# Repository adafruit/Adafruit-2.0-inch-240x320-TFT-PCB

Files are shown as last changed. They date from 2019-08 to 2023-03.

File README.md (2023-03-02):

## Adafruit 2.0" 320x240 Color IPS TFT Display with microSD Card Breakout PCB

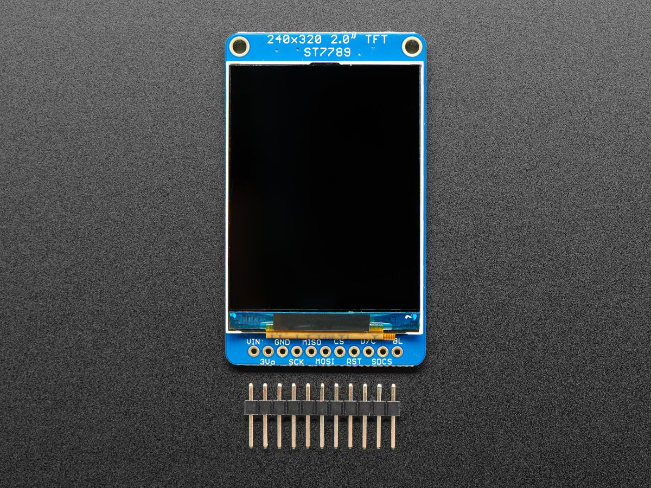
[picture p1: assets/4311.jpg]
<a href="http://www.adafruit.com/products/4311"><br/>
Click here to purchase one from the Adafruit shop</a>

PCB files for the Adafruit 2.0" 320x240 Color IPS TFT Display with microSD Card Breakout. 

Format is EagleCAD schematic and board layout
* https://www.adafruit.com/product/4311

### Description

This gorgeous IPS display breakout is the best way to add a small, colorful, and bright display to any project, with excellent visibility from any angle. Since the display uses 4-wire SPI to communicate and has its own pixel-addressable frame buffer, it can be used with every kind of microcontroller. Even a very small one with low memory and few pins available!

The 2.0" display has 320x240 color pixels. Unlike the low cost "Nokia 6110" and similar LCD displays, which are CSTN type and thus have poor color and slow refresh, this display is a true TFT! Not only that, but its an IPS display for vivid color and high-angle visibility. The TFT driver (ST7789) can display full 18-bit color (262,144 shades), but almost all drivers will use just 16-bit color. The TFT will always come with the same driver chip so there's no worries that your code will not work from one to the other.

The breakout has the TFT display soldered on (it uses a delicate flex-circuit connector) as well as a ultra-low-dropout 3.3V regulator, auto-reset circuitry, and a 3/5V level shifter so you can use it with 3.3V or 5V power and logic. We also had a little space so we placed a microSD card holder so you can easily load full color bitmaps from a FAT16/FAT32 formatted microSD card. The microSD card is not included, but you can pick one up here.

Of course, we wouldn't just leave you with a datasheet and a "good luck!" - we've written a full open source graphics library that can draw pixels, lines, rectangles, circles, text, and bitmaps as well as example code. The code is written for Arduino but can be easily ported to your favorite microcontroller! Wiring is easy, we strongly encourage using the hardware SPI pins of your Arduino as software SPI is noticeably slower when dealing with this size display.

New! As of February 2023, this display breakout also features an 18-pin "EYESPI" standard FPC connector with flip-top connector. You can use an 18-pin 0.5mm pitch FPC cable to connect to the display over SPI and I2C, respectively. Great for when you want to skip soldering all those headers. 

### License

Adafruit invests time and resources providing this open source design, please support Adafruit and open-source hardware by purchasing products from [Adafruit](https://www.adafruit.com)!

Designed by Limor Fried/Ladyada for Adafruit Industries.

Creative Commons Attribution/Share-Alike, all text above must be included in any redistribution. 
See license.txt for additional details.

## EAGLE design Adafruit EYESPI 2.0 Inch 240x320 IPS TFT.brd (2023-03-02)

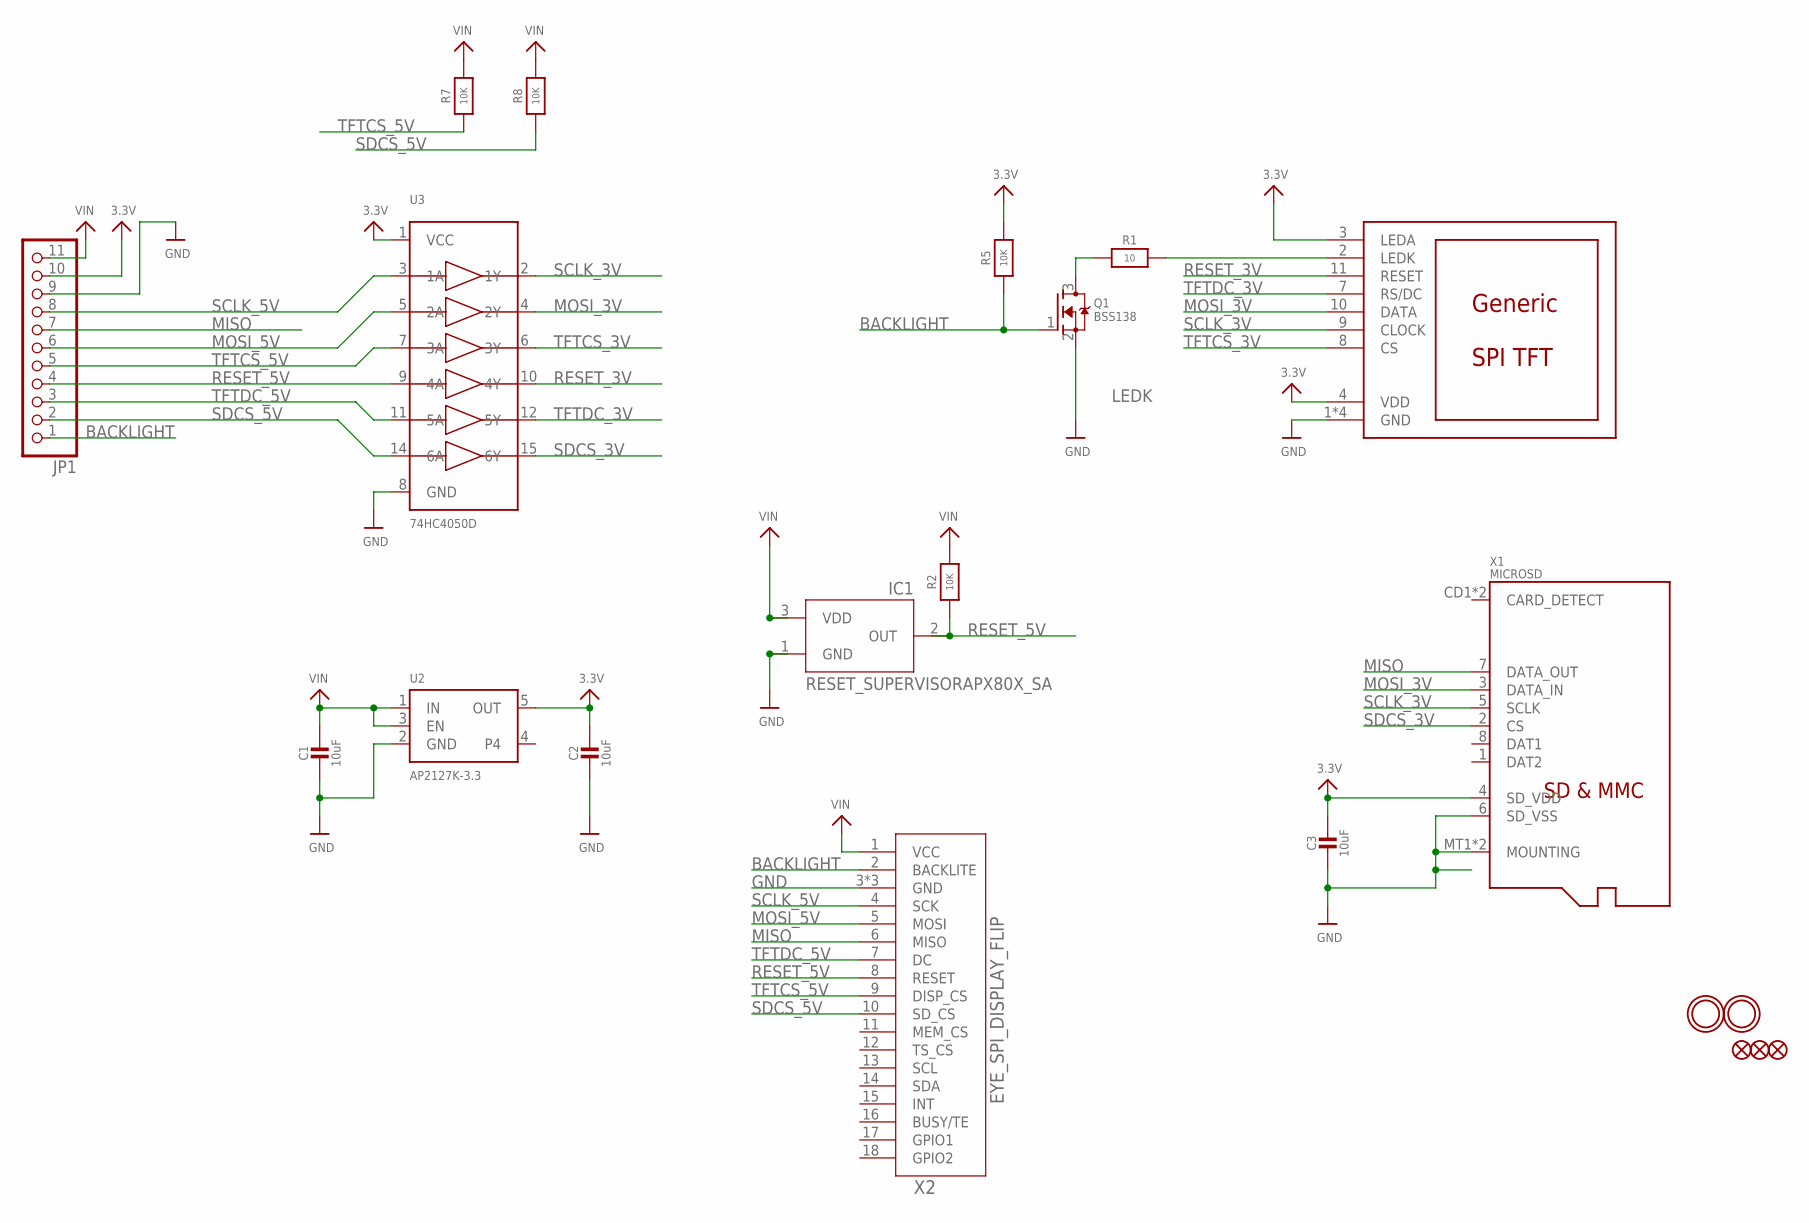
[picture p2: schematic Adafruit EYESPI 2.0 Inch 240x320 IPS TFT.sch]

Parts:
C1, C2, C3: 10uF; 0805-NO
DISP1: DISP_LCD_GENERIC_SPI_2.0IN_240X320; TFT_2.0IN_240X320_12P
FID1, FID2, FID3: FIDUCIAL_1MM
IC1: RESET_SUPERVISORAPX80X_SA; SOT23-WIDE
JP1: HEADER-1X1176MIL; 1X11_ROUND_76
Q1: BSS138; SOT23-R
R1: 10; 0805-NO
R2, R5, R7, R8: 10K; 0805-NO
U2: AP2127K-3.3; SOT23-5
U3: 74HC4050D; SOIC16
U$3, U$4: MOUNTINGHOLE2.5; MOUNTINGHOLE_2.5_PLATED
X1: MICROSD
X2: EYE_SPI_DISPLAY_FLIP; EYE_SPI_DISPLAY_BOTCONTACT

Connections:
3.3V: C2.1, C3.1, DISP1.3 (LEDA), DISP1.4 (VDD), JP1.10, R5.2, U2.5 (OUT), U3.1 (VCC), X1.4 (SD_VDD)
BACKLIGHT: JP1.1, Q1.1 (G), R5.1, X2.2 (BACKLITE)
GND: C1.2, C2.2, C3.2, DISP1.1 (GND), DISP1.5 (GND), DISP1.6 (GND), DISP1.12 (GND), IC1.1 (GND), JP1.9, Q1.2 (S), U2.2 (GND), U3.8 (GND), X1.6 (SD_VSS), X1.MT1 (MOUNTING), X1.MT2 (MOUNTING), X2.3 (GND), X2.SUPPORT1 (GND), X2.SUPPORT2 (GND)
LEDK: Q1.3 (D), R1.1
MISO: JP1.7, X1.7 (DATA_OUT), X2.6 (MISO)
MOSI_3V: DISP1.10 (DATA), U3.4 (2Y), X1.3 (DATA_IN)
MOSI_5V: JP1.6, U3.5 (2A), X2.5 (MOSI)
unnamed: DISP1.2 (LEDK), R1.2
RESET_3V: DISP1.11 (RESET), U3.10 (4Y)
RESET_5V: IC1.2 (OUT), JP1.4, R2.1, U3.9 (4A), X2.8 (RESET)
SCLK_3V: DISP1.9 (CLOCK), U3.2 (1Y), X1.5 (SCLK)
SCLK_5V: JP1.8, U3.3 (1A), X2.4 (SCK)
SDCS_3V: U3.15 (6Y), X1.2 (CS)
SDCS_5V: JP1.2, R8.1, U3.14 (6A), X2.10 (SD_CS)
TFTCS_3V: DISP1.8 (CS), U3.6 (3Y)
TFTCS_5V: JP1.5, R7.1, U3.7 (3A), X2.9 (DISP_CS)
TFTDC_3V: DISP1.7 (RS/DC), U3.12 (5Y)
TFTDC_5V: JP1.3, U3.11 (5A), X2.7 (DC)
VIN: C1.1, IC1.3 (VDD), JP1.11, R2.2, R7.2, R8.2, U2.1 (IN), U2.3 (EN), X2.1 (VCC)

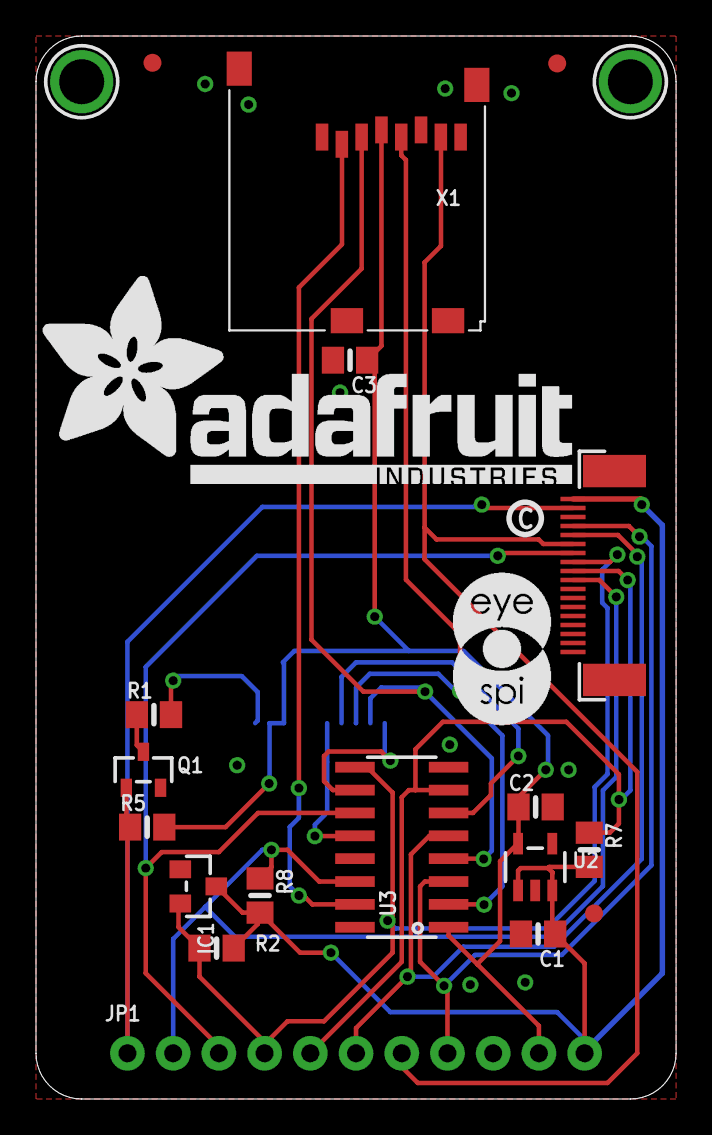
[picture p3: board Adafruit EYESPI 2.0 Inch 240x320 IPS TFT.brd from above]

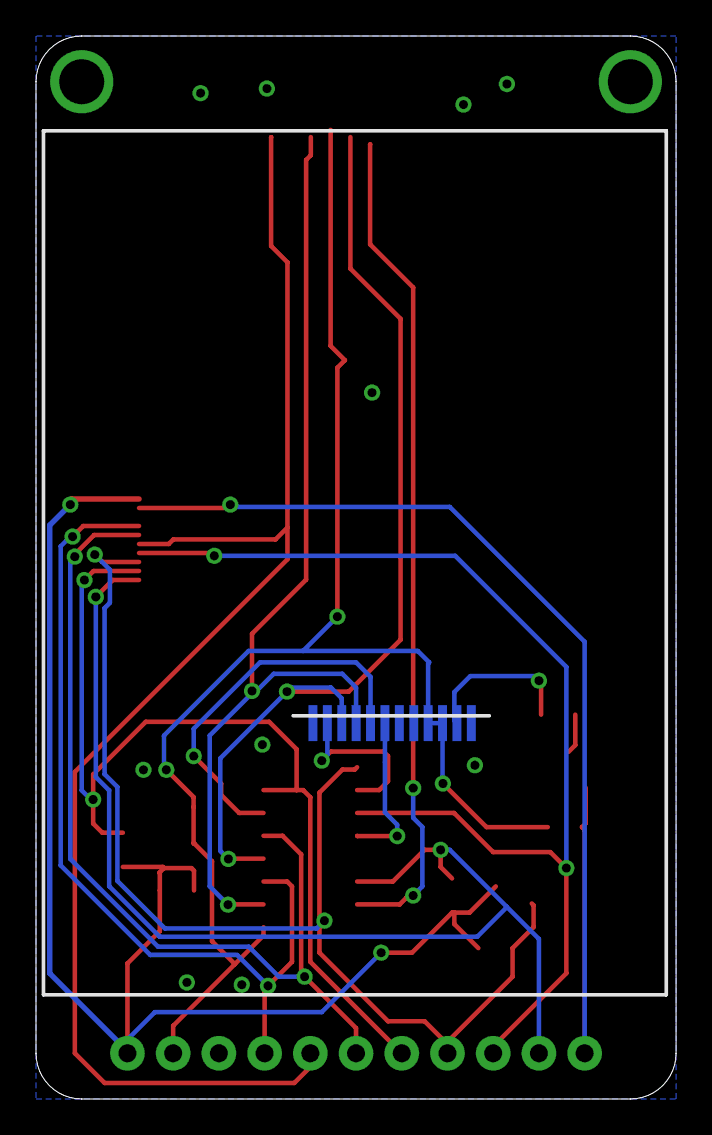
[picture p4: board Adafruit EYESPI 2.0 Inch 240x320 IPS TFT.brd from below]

Board: 2 copper layers, 35.6 x 59.1 mm, 48 parts (13 on the bottom side), 19 nets.

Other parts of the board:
PLABEL0: PLABEL0
PLABEL1: PLABEL1
PLABEL2: PLABEL2
PLABEL3: PLABEL3
PLABEL4: PLABEL4
PLABEL5: PLABEL5
PLABEL6: PLABEL6
PLABEL7: PLABEL7
PLABEL8: PLABEL8
PLABEL9: PLABEL9
PLABEL10: PLABEL10
PLABEL11: PLABEL11
PLABEL12: PLABEL12
PLABEL13: PLABEL13
PLABEL14: PLABEL14
PLABEL15: PLABEL15
PLABEL16: PLABEL16
PLABEL17: PLABEL17
PLABEL18: PLABEL18
PLABEL19: PLABEL19
PLABEL20: PLABEL20
PLABEL21: PLABEL21
PLABEL22: PLABEL22
PLABEL23: PLABEL23
U$20: ADAFRUIT_TEXT_30MM
U$24: PCBFEAT-REV-040
U$28: EYESPI_MINI_LOGO

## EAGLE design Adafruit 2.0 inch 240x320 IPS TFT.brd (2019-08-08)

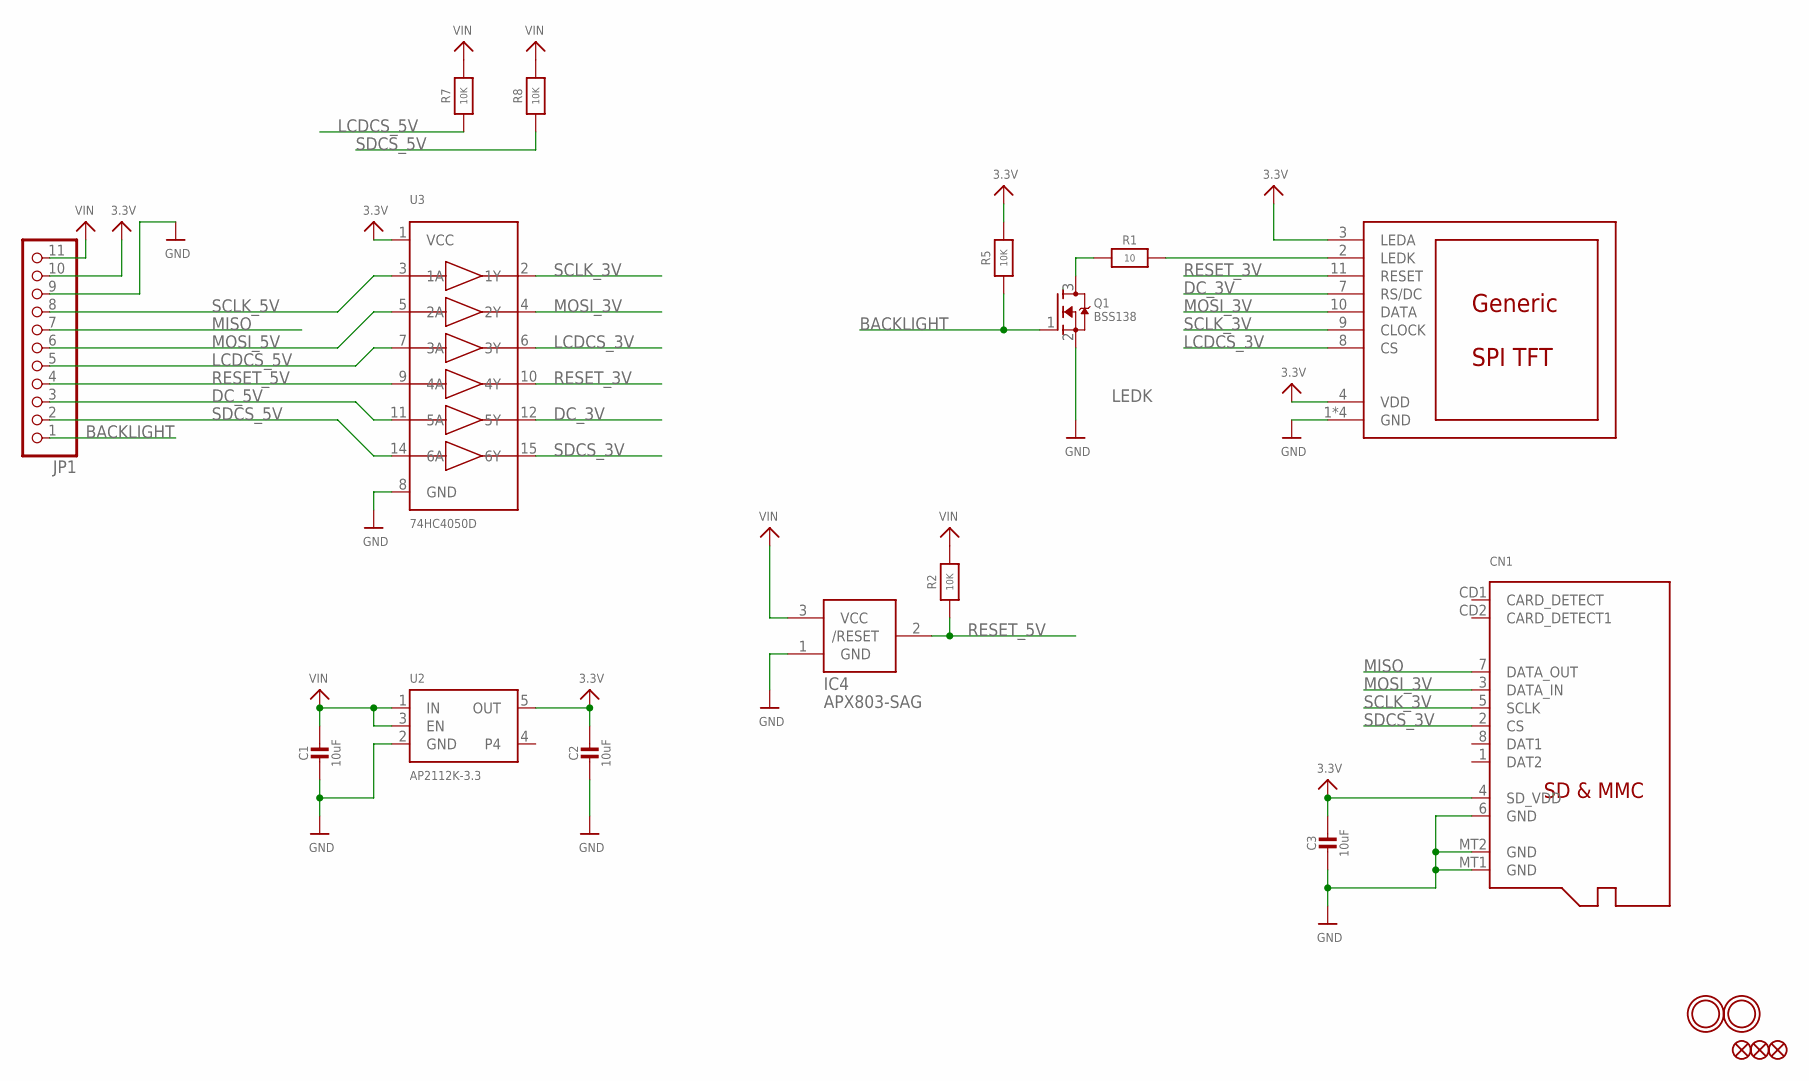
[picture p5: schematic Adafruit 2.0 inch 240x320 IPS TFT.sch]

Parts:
C1, C2, C3: 10uF; 0805-NO
CN1: MICROSD
DISP1: DISP_LCD_GENERIC_SPI_2.0IN_240X320; TFT_2.0IN_240X320_12P
FID1, FID2, FID3: FIDUCIAL_1MM
IC4: APX803-SAG; SOT23
JP1: HEADER-1X1176MIL; 1X11_ROUND_76
Q1: BSS138; SOT23-R
R1: 10; 0805-NO
R2, R5, R7, R8: 10K; 0805-NO
U2: AP2112K-3.3; SOT23-5
U3: 74HC4050D; SOIC16
U$3, U$4: MOUNTINGHOLE2.5; MOUNTINGHOLE_2.5_PLATED

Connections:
3.3V: C2.1, C3.1, CN1.4 (SD_VDD), DISP1.3 (LEDA), DISP1.4 (VDD), JP1.10, R5.2, U2.5 (OUT), U3.1 (VCC)
BACKLIGHT: JP1.1, Q1.1 (G), R5.1
DC_3V: DISP1.7 (RS/DC), U3.12 (5Y)
DC_5V: JP1.3, U3.11 (5A)
GND: C1.2, C2.2, C3.2, CN1.6 (GND), CN1.MT1 (GND), CN1.MT2 (GND), DISP1.1 (GND), DISP1.5 (GND), DISP1.6 (GND), DISP1.12 (GND), IC4.1 (GND), JP1.9, Q1.2 (S), U2.2 (GND), U3.8 (GND)
LCDCS_3V: DISP1.8 (CS), U3.6 (3Y)
LCDCS_5V: JP1.5, R7.1, U3.7 (3A)
LEDK: Q1.3 (D), R1.1
MISO: CN1.7 (DATA_OUT), JP1.7
MOSI_3V: CN1.3 (DATA_IN), DISP1.10 (DATA), U3.4 (2Y)
MOSI_5V: JP1.6, U3.5 (2A)
unnamed: DISP1.2 (LEDK), R1.2
RESET_3V: DISP1.11 (RESET), U3.10 (4Y)
RESET_5V: IC4.2 (/RESET), JP1.4, R2.1, U3.9 (4A)
SCLK_3V: CN1.5 (SCLK), DISP1.9 (CLOCK), U3.2 (1Y)
SCLK_5V: JP1.8, U3.3 (1A)
SDCS_3V: CN1.2 (CS), U3.15 (6Y)
SDCS_5V: JP1.2, R8.1, U3.14 (6A)
VIN: C1.1, IC4.3 (VCC), JP1.11, R2.2, R7.2, R8.2, U2.1 (IN), U2.3 (EN)

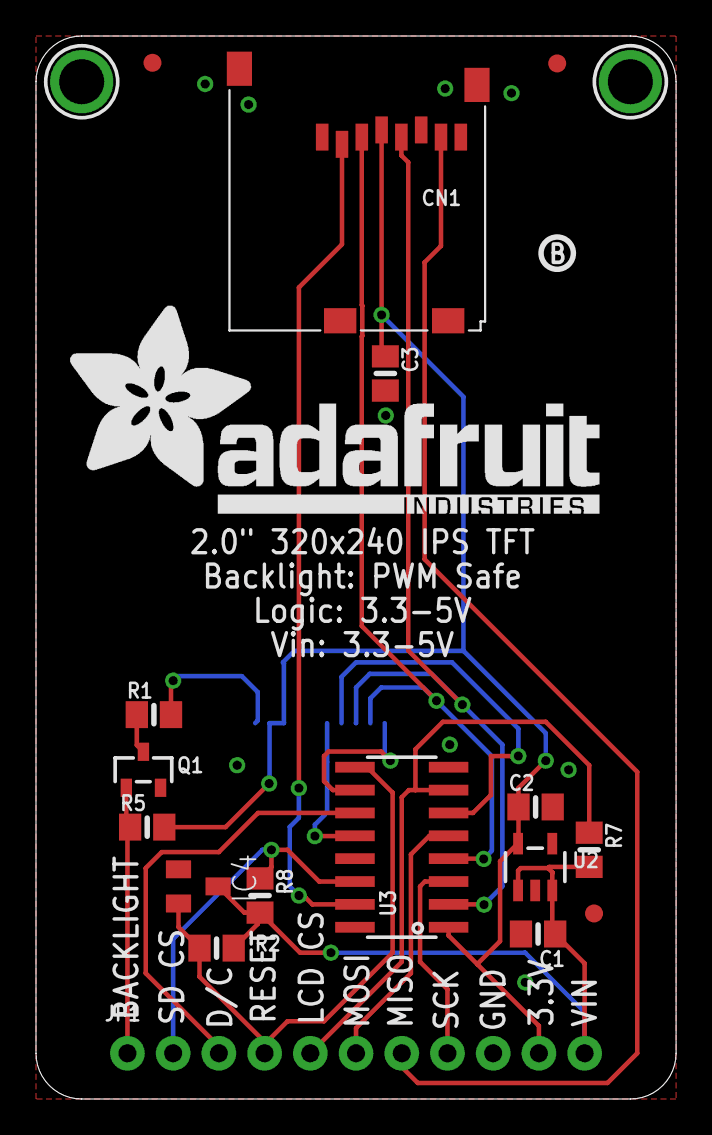
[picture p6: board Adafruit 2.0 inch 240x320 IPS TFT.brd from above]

Board: 2 copper layers, 35.6 x 59.1 mm, 22 parts (1 on the bottom side), 19 nets.

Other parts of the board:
U$20: ADAFRUIT_TEXT_30MM
U$24: PCBFEAT-REV-040

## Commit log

2019-08-08 Adding board/repo files.
    [Adafruit 2.0 inch 240x320 IPS TFT.brd, Adafruit 2.0 inch 240x320 IPS TFT.sch]
2023-03-02 adding EYESPI files and updating readme
    [Adafruit EYESPI 2.0 Inch 240x320 IPS TFT.brd, Adafruit EYESPI 2.0 Inch 240x320 IPS TFT.sch]
